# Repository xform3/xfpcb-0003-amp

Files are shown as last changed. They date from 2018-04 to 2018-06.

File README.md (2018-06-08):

Xform3

# XFPCB-0003 Class-AB Amplifier 20-30W LM1875 or TDA2030

## Variation 1 LM1875
The LM1875 is a monolithic power amplifier offering very low distortion and high quality performance for consumer audio applications.
#### Specifications 
- Load: 4Ω - 8Ω 
- Output Power: 30W
- Supply Voltage 12V-36V(±18)
#### Features
- Low Distortion: 0.015%, 1 kHz, 20 W
- Wide Power Bandwidth: 70 kHz
- High Current Capability: 4A
- Protection for AC and DC Short Circuits to Ground

## Variation 2 TDA2030
The TDA2030 is a monolithic integrated circuit in Pentawattpackage, intended for use as a low frequency class AB amplifier.
#### Specifications 
- Load: 4Ω - 8Ω 
- Supply Voltage ±18(36)
- Output Power: 20W
#### Features
- Low harmonic and cross-over distortion
- Short circuit protection system and thermal shut-down system

### [Use with: XFPCB-0004 Regulated Bipolar Power Supply](https://github.com/xform3/xfpcb-0004-psu)

# Included Files:
* [xf3_amp](https://github.com/xform3/xfpcb-0003-amp/tree/master/xf3_amp)  - *KiCAD Project Files*
* [xf3_amp_gerbers_masks](https://github.com/xform3/xfpcb-0003-amp/tree/master/xf3_amp_gerbers_masks) - *PCB Gerber, Drill, Silk/Solder Masks, Positive and Negative plots*
* [xf3-KiCad-Library](https://github.com/xform3/xf3-KiCad-Library)  - *KiCAD Library Files; footprints, .step and .wrl component models, schema lib.*

## Schematic
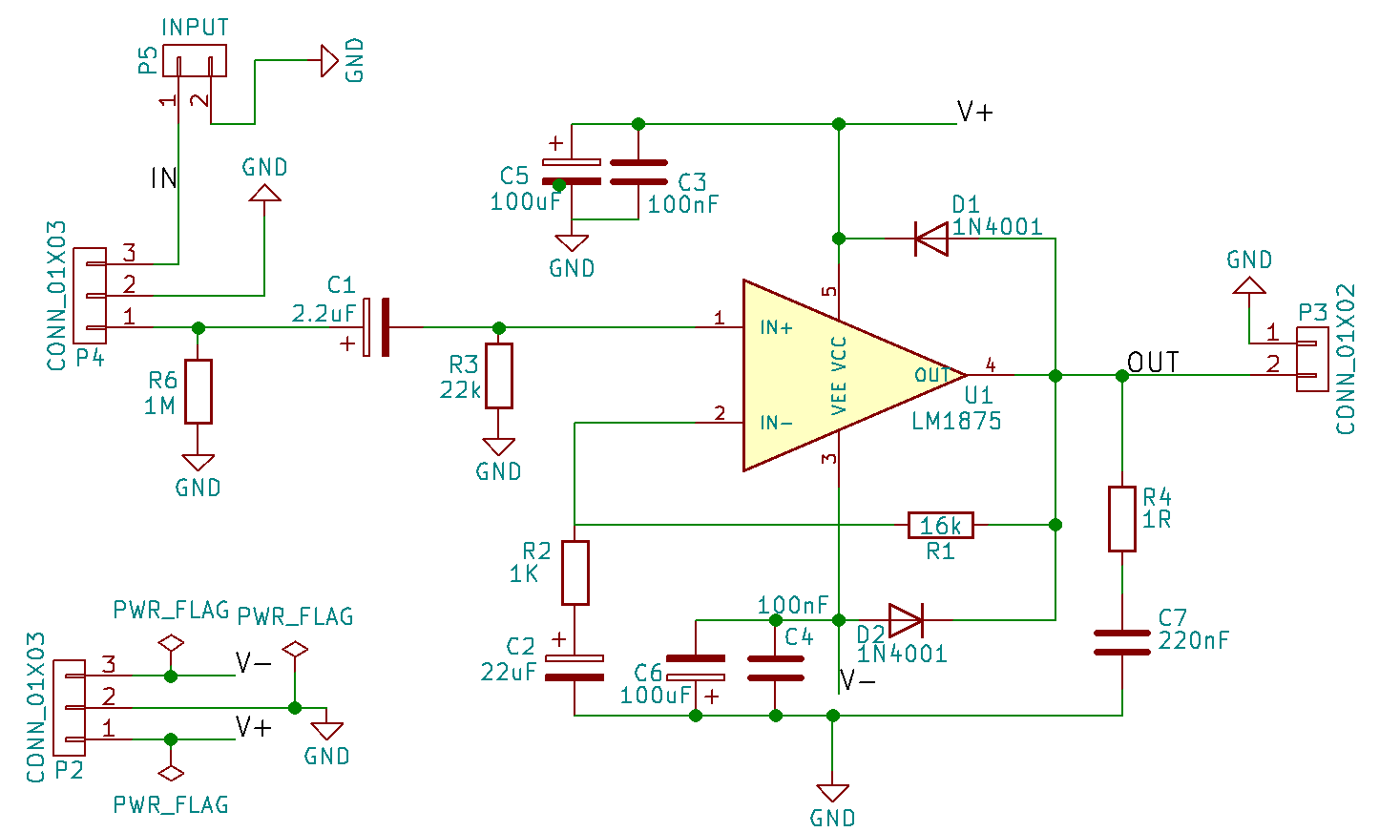
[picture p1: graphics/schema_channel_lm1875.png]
Xform3 XFPCB-0003 Class-AB Amplifier KiCAD Schema


## Application
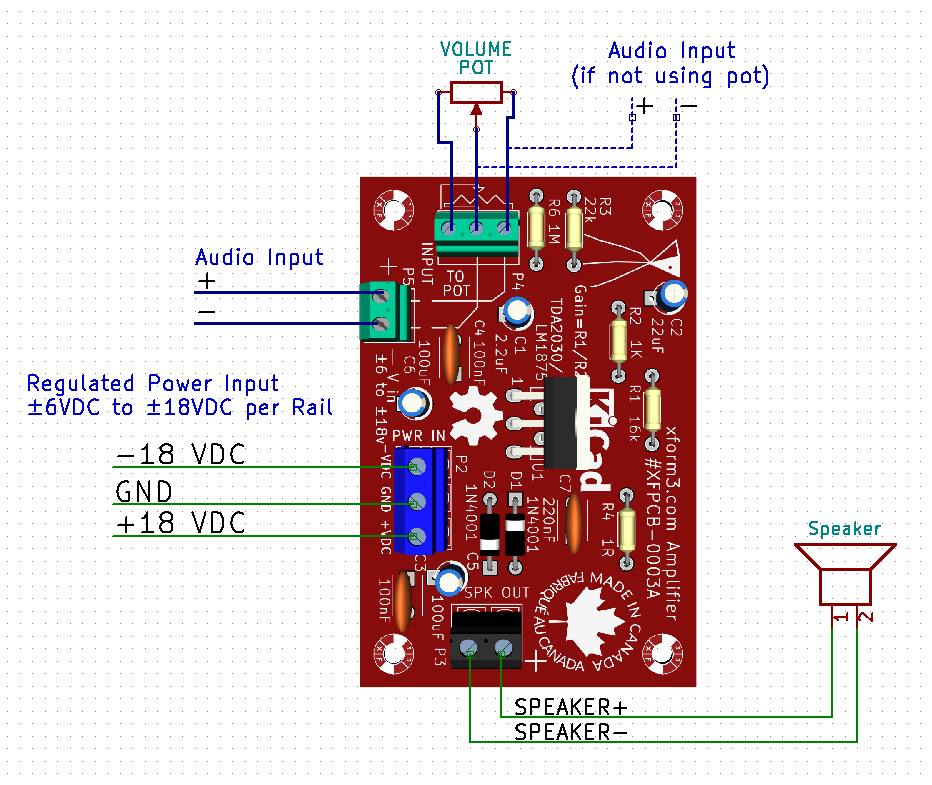
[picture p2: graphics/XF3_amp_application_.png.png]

 
## KiCad 3D
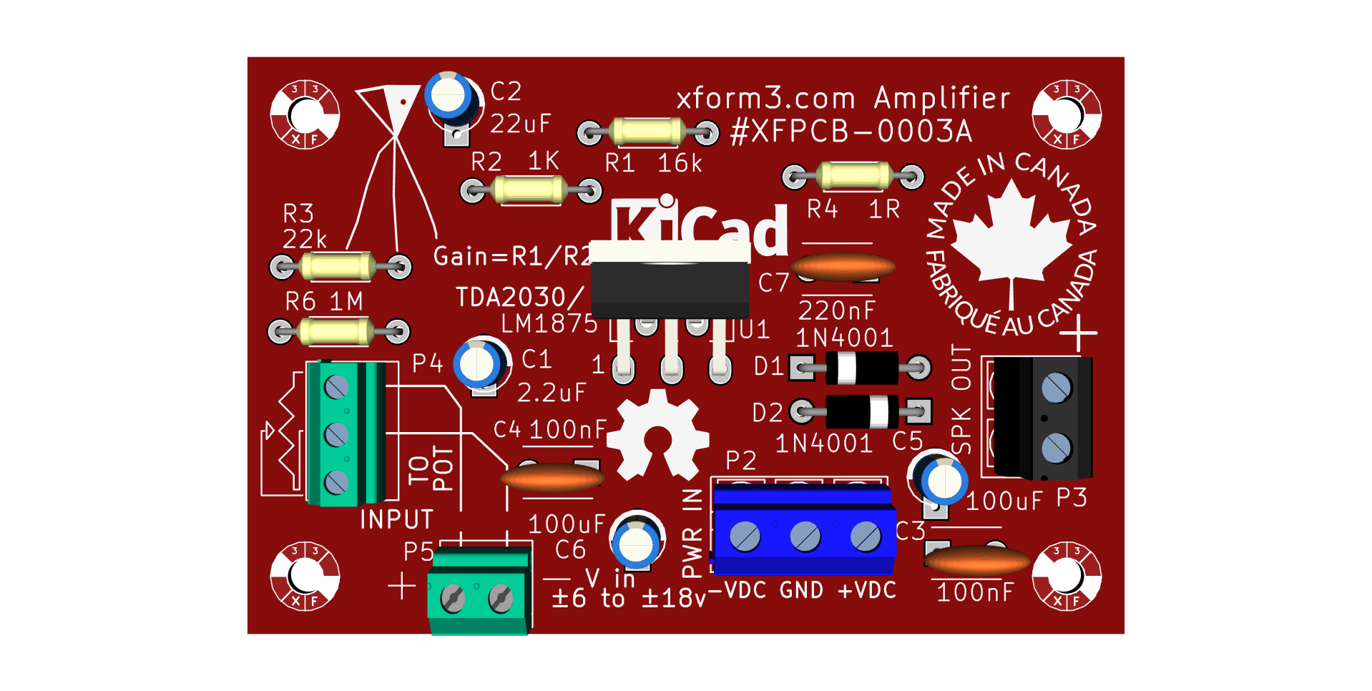
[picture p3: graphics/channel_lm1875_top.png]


## PCB
Xform3 XFPCB-0003 Class-AB Amplifier

## Prototype
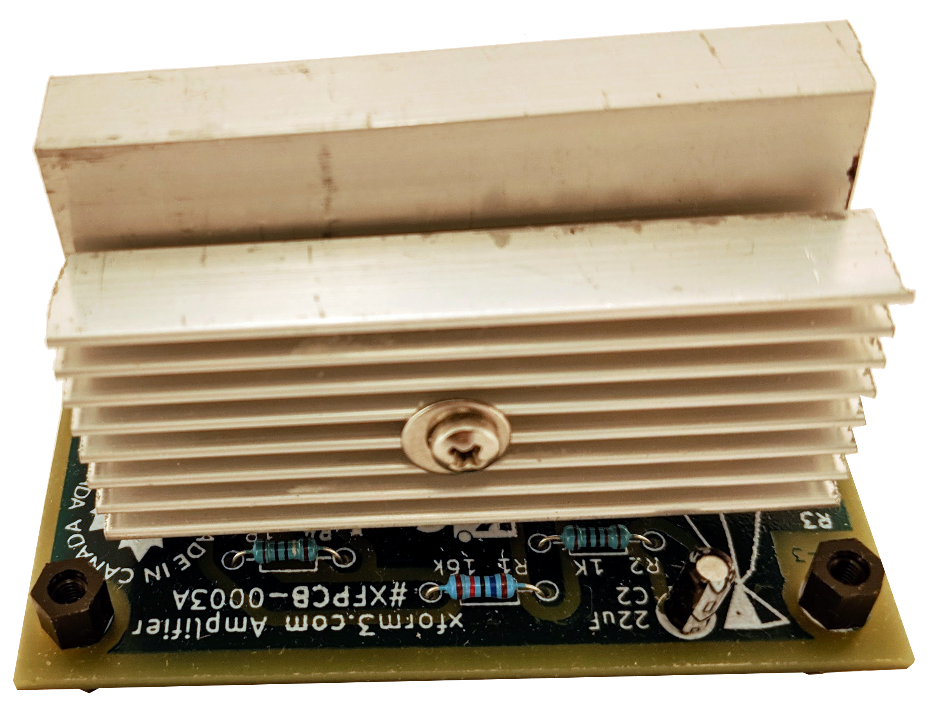
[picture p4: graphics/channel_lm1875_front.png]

Xform3 XFPCB-0003 Class-AB Amplifier

## Amplifier [Using: XFPCB-0004 Regulated Bipolar Power Supply](https://github.com/xform3/xfpcb-0004-psu)
Xform3 XFPCB-0003 Class-AB Amplifier
Xform3 XFPCB-0003 Class-AB Amplifier

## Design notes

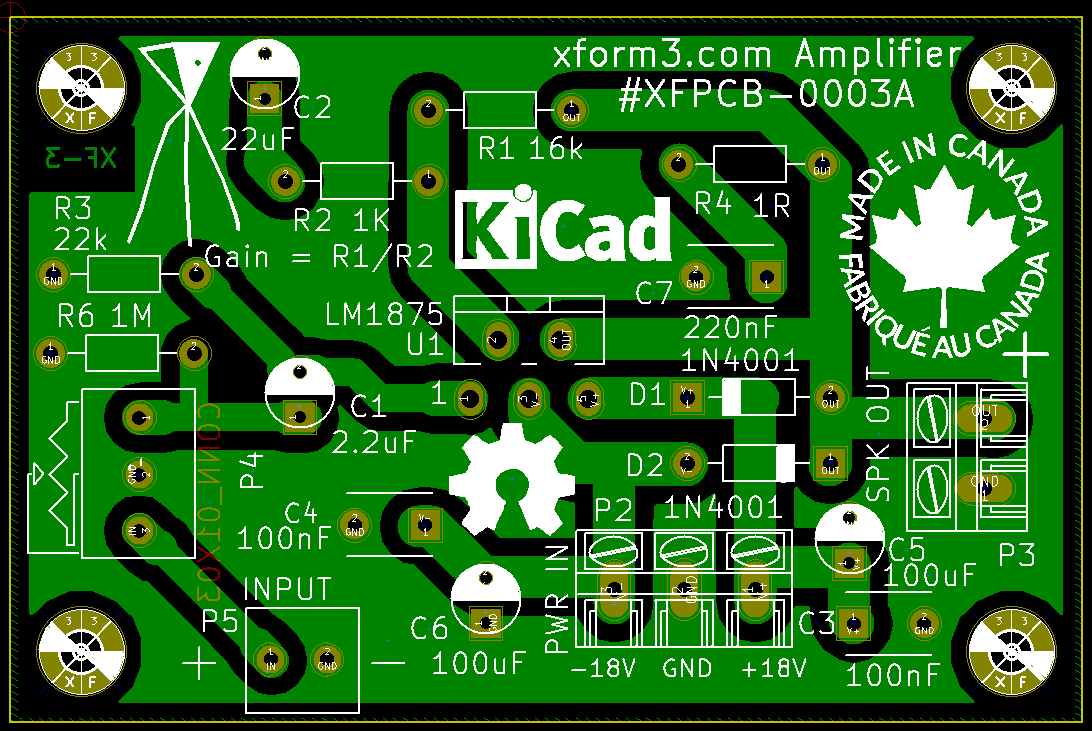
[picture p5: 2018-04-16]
graphics/pcb_lm1875.png

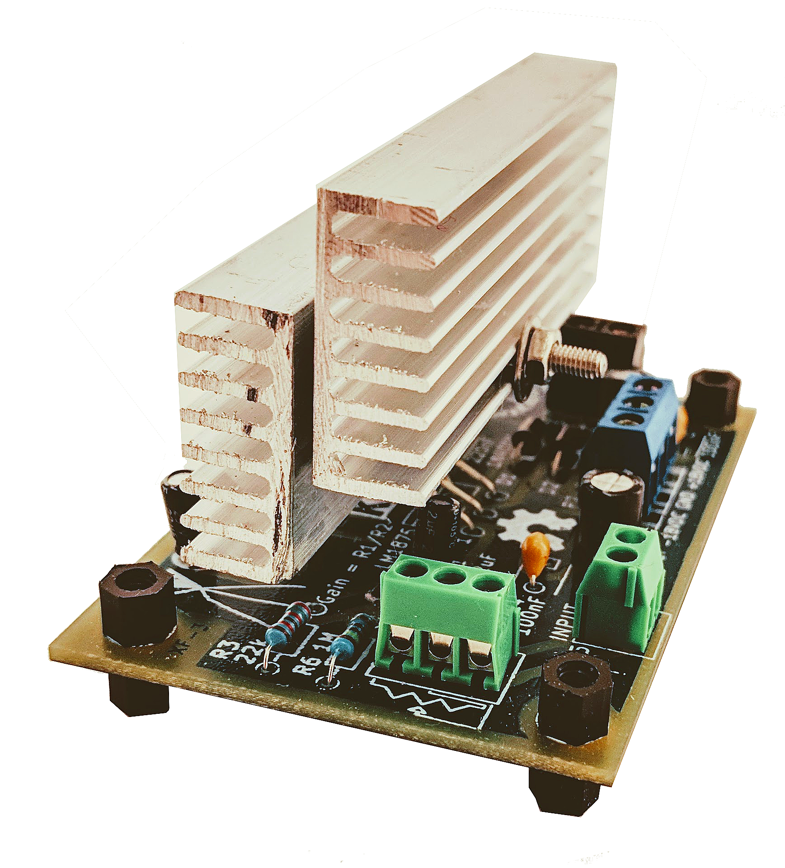
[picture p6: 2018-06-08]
graphics/channel_lside.png

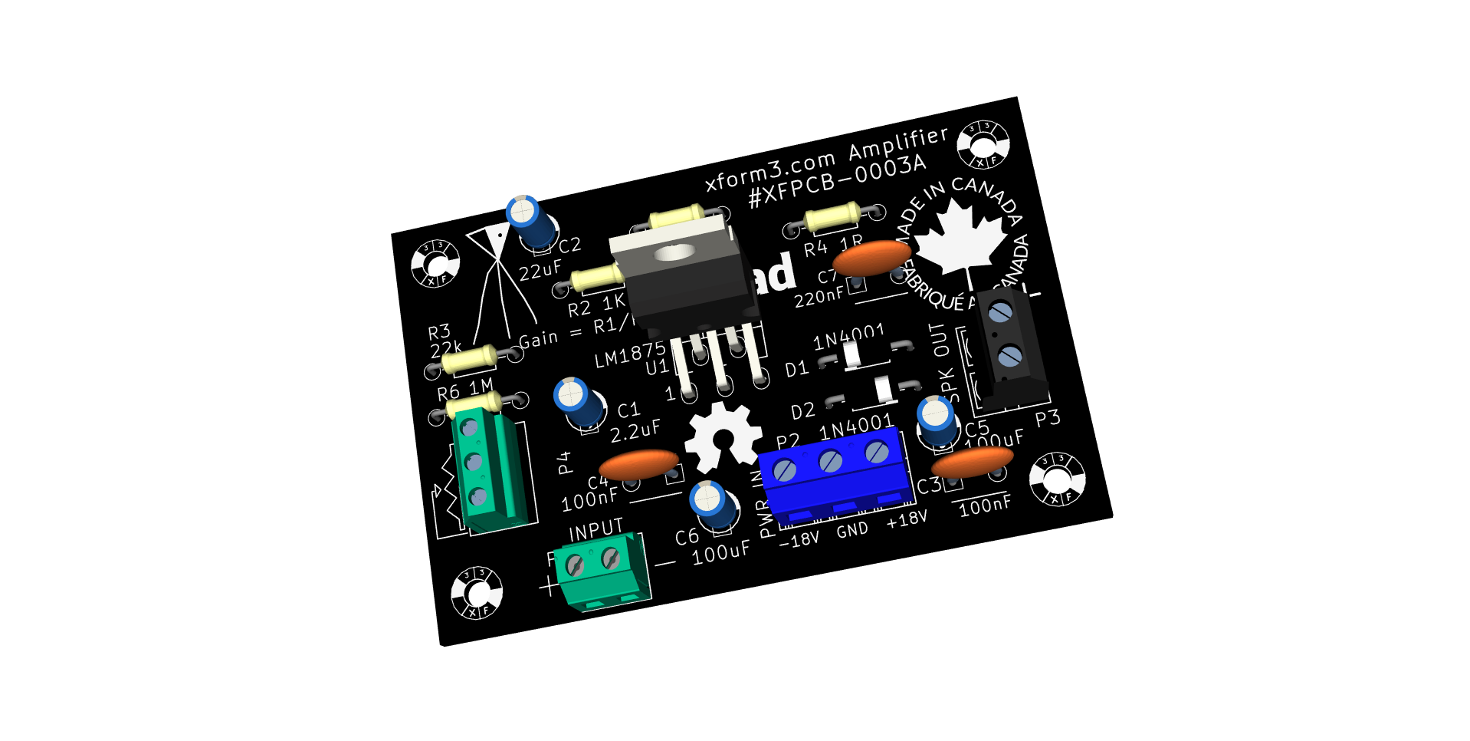
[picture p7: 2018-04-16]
graphics/channel_lm1875.png

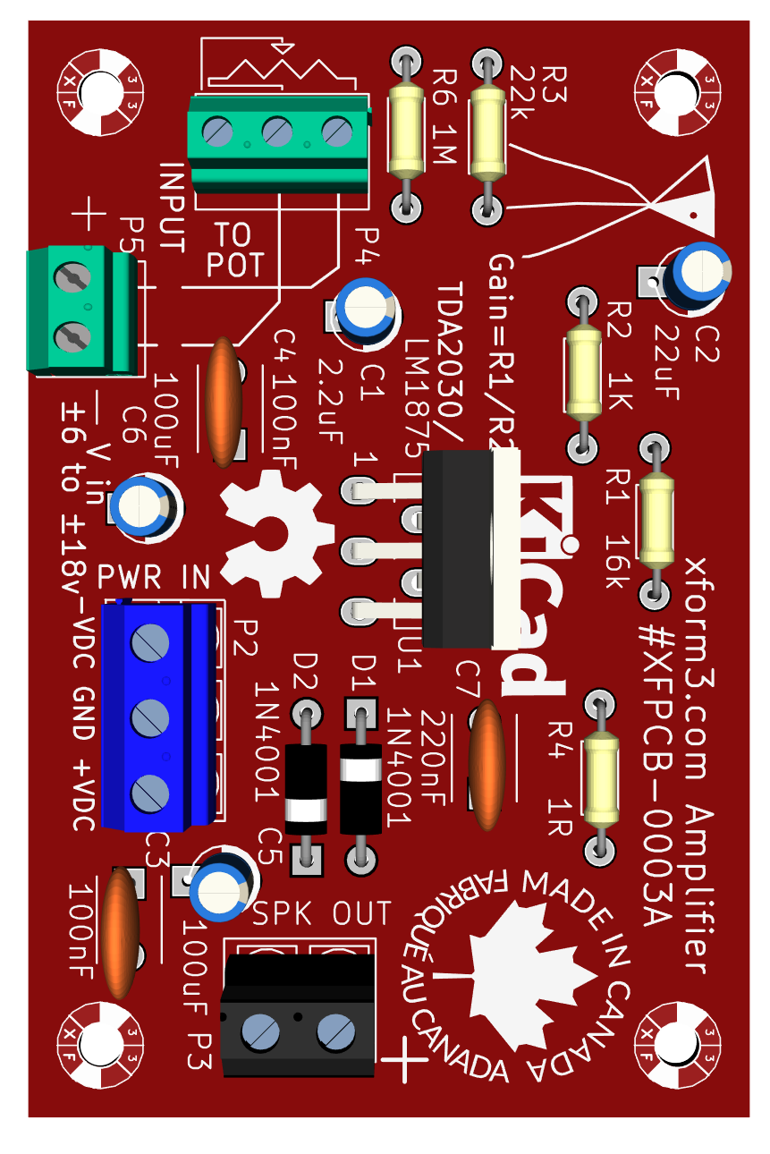
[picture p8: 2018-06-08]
graphics/channel_lm1875_top2.png

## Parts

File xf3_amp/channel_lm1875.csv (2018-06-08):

Title
Revision
Date
Generated | Sat 19 May 2018 12:51:55 AM EDT
Company
Comment 1
Comment 2
Comment 3
Comment 4
Total Parts | 23
Total Unique Parts | 17
Ref | Qty | Value | Footprint | Datasheet
C1 | 1 | 2.2uF | x_components:x_CapRadial7mm
C2 | 1 | 22uF | x_components:x_CapRadial7mm
C3 C4 | 2 | 100nF | x_components:x_CapDisk9mm
C5 C6 | 2 | 100uF | x_components:x_CapRadial7mm
C7 | 1 | 220nF | x_components:x_CapDisk9mm
D1 D2 | 2 | 1N4001 | x_components:x_Diode
P1 P6 P7 P8 | 4 | xhole | x_components:x_HoleRound
P2 | 1 | CONN_01X03 | x_components:x_PhoenixX3
P3 | 1 | CONN_01X02 | x_components:x_PhoenixX2
P4 | 1 | CONN_01X03 | x_components:x_PotConn
P5 | 1 | INPUT | x_components:x_PhoenixX2mini
R1 | 1 | 16k | x_components:x_ResistorHorizontalRM10mm
R2 | 1 | 1K | x_components:x_ResistorHorizontalRM10mm
R3 | 1 | 22k | x_components:x_ResistorHorizontalRM10mm
R4 | 1 | 1R | x_components:x_ResistorHorizontalRM10mm
R6 | 1 | 1M | x_components:x_ResistorHorizontalRM10mm
U1 | 1 | LM1875 | x_components:x_TDA
BOM made with KICAD_BOM_WIZARD (https://github.com/HashDefineElectronics/KiCad_BOM_Wizard.git)
Generated Sat 19 May 2018 12:51:55 AM EDT

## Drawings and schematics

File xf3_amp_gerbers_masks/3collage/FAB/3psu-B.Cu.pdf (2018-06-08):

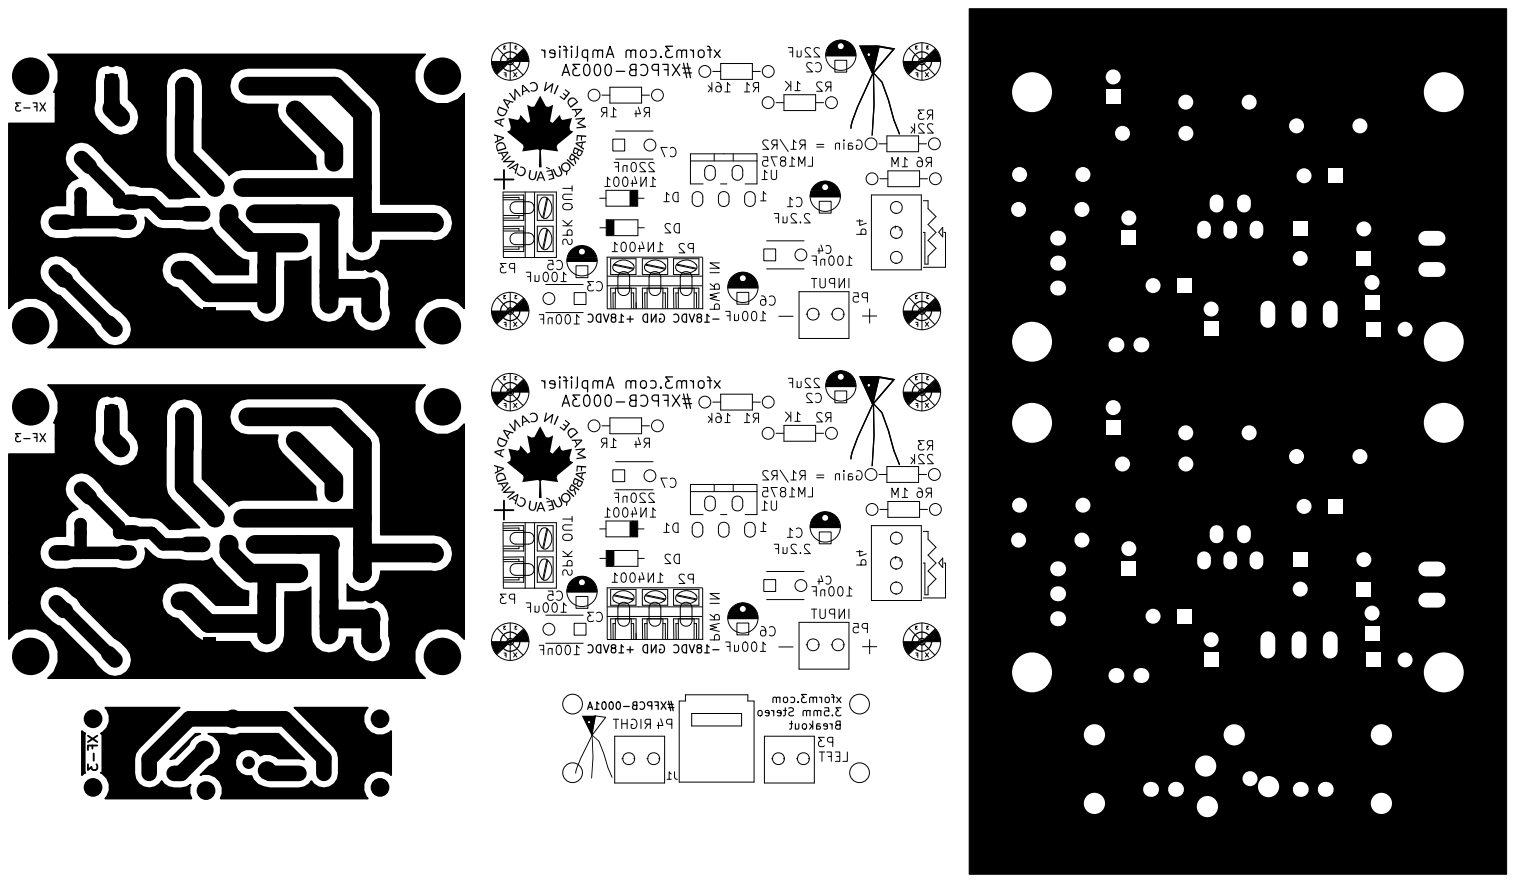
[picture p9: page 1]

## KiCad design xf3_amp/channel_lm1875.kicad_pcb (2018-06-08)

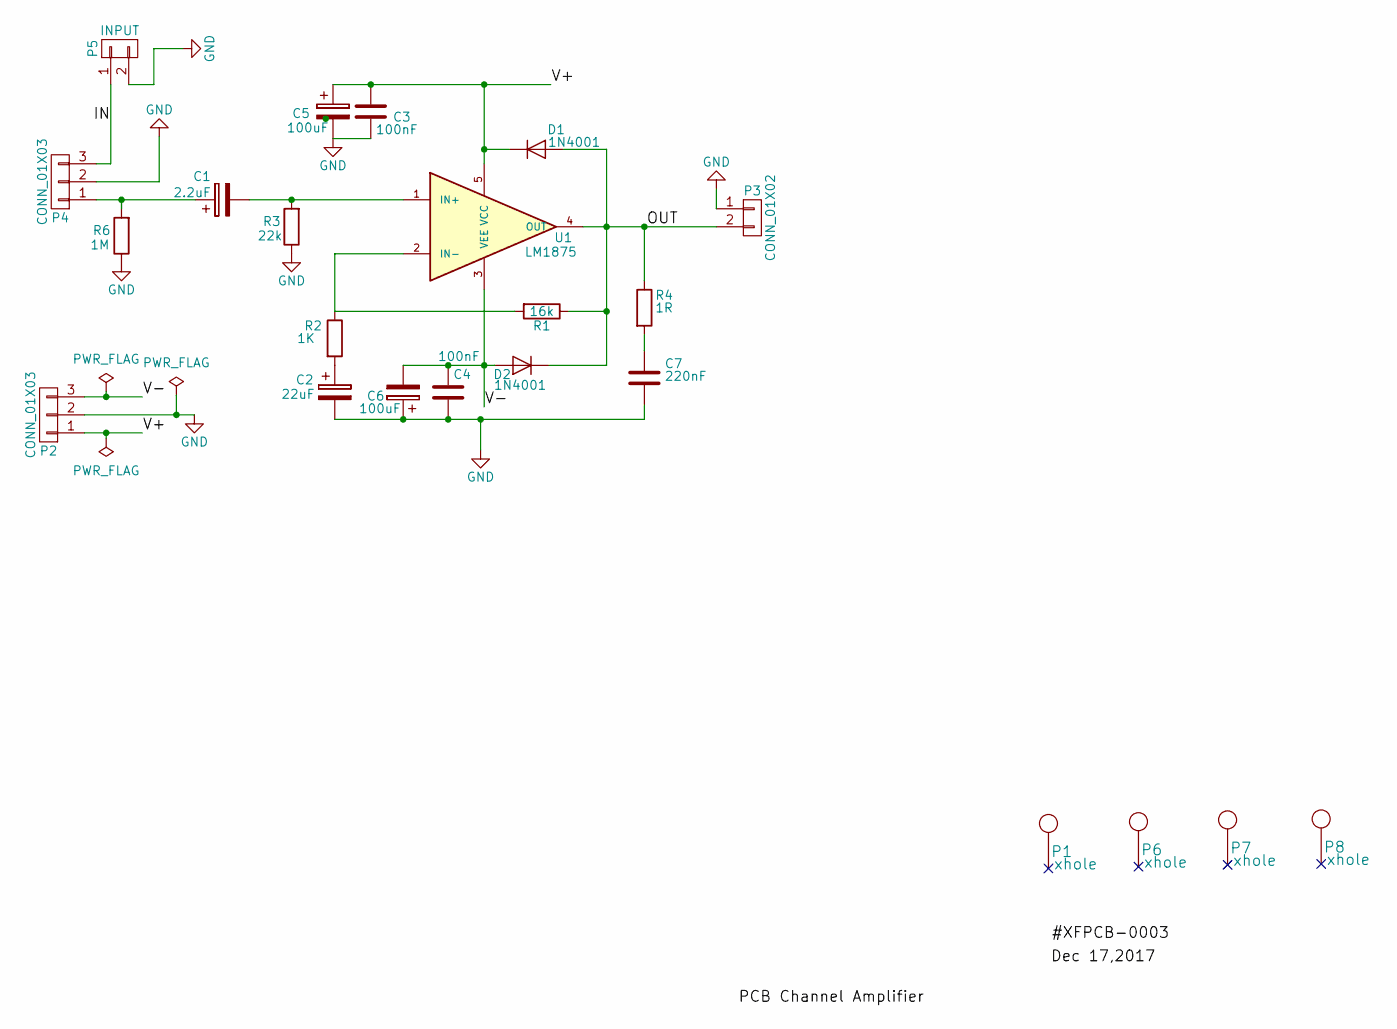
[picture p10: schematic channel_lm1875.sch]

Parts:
C1: 2.2uF; x_CapRadial7mm
C2: 22uF; x_CapRadial7mm
C3, C4: 100nF; x_CapDisk9mm
C5, C6: 100uF; x_CapRadial7mm
C7: 220nF; x_CapDisk9mm
D1, D2: 1N4001; x_Diode
P1, P6, P7, P8: xhole; x_HoleRound
P2: CONN_01X03; x_PhoenixX3
P3: CONN_01X02; x_PhoenixX2
P4: CONN_01X03; x_PotConn
P5: INPUT; x_PhoenixX2mini
R1: 16k; x_ResistorHorizontalRM10mm
R2: 1K; x_ResistorHorizontalRM10mm
R3: 22k; x_ResistorHorizontalRM10mm
R4: 1R; x_ResistorHorizontalRM10mm
R6: 1M; x_ResistorHorizontalRM10mm
U1: LM1875; x_TDA

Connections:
/IN: P4.3, P5.1
/OUT: D1.2 (A), D2.1 (K), P3.2, R1.1, R4.1, U1.4 (OUT)
/V+: C3.1, C5.1, D1.1 (K), P2.1, U1.5 (VCC)
/V-: C4.1, C6.2, D2.2 (A), P2.3, U1.3 (VEE)
GND: C2.2, C3.2, C4.2, C5.2, C6.1, C7.2, P2.2, P3.1, P4.2, P5.2, R3.1, R6.1
unnamed: C1.1, P4.1, R6.2
unnamed: C1.2, R3.2, U1.1 (IN+)
unnamed: C2.1, R2.2
unnamed: C7.1, R4.2
unnamed: R1.2, R2.1, U1.2 (IN-)

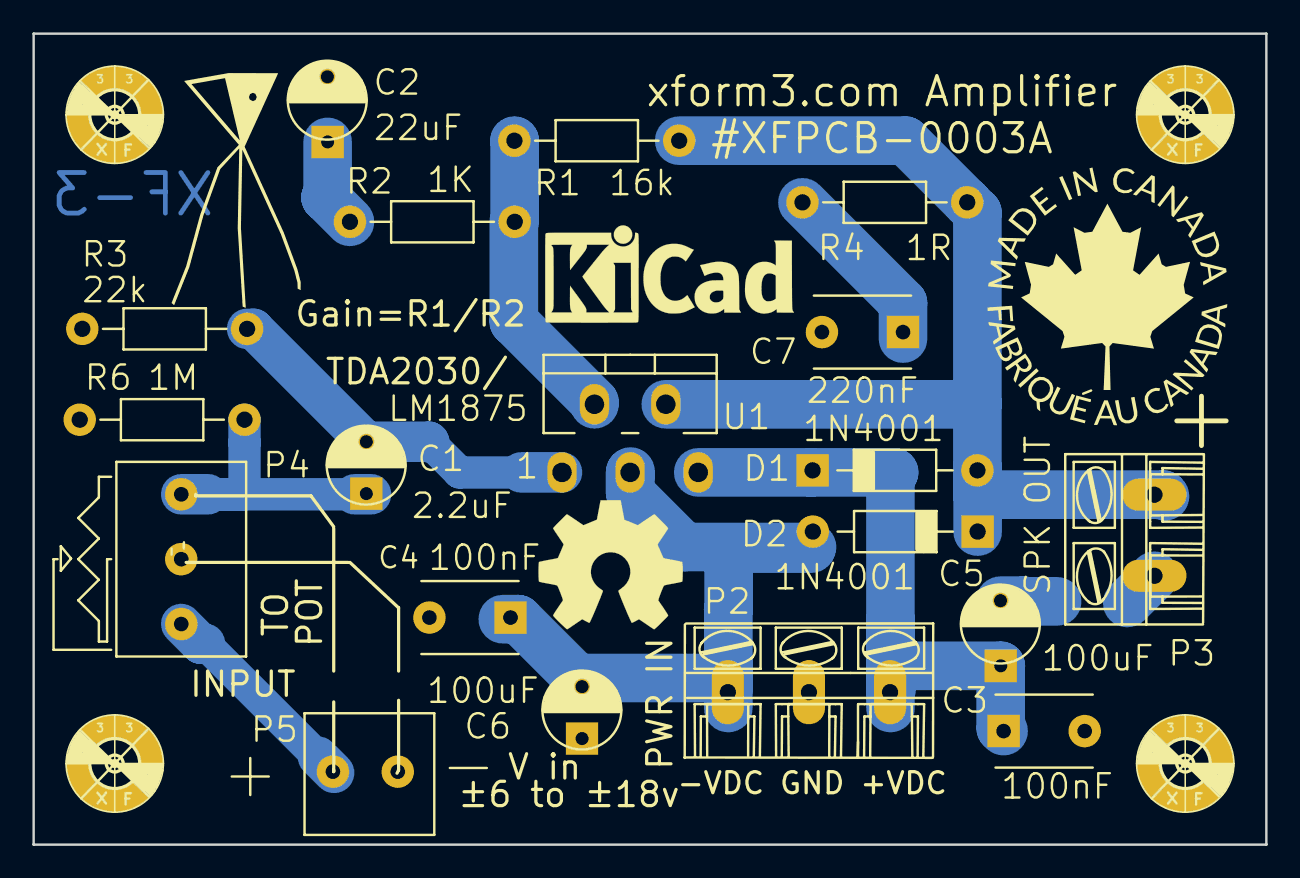
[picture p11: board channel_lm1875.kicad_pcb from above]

Board: 2 copper layers, 76.0 x 50.0 mm, 25 parts (0 on the bottom side), 10 nets.

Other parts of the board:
svg2mod: G***; x_gx_xform_8x14_Silk
svg2mod#2: G***; x_gx_madeincanada
